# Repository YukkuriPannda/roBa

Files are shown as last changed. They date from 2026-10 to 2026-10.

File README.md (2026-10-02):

# roBa

## 個人用ケース改造（FreeCAD / PLA）

このフォークではroBa v3を基準に、既存の折り畳みテンティング案をFreeCADで編集・再生成できる構成へ移植しています。

- [FreeCAD版の起動・編集・出力](case/v3/freecad/README.md)
- [自然言語の要望から改造する手順とデータの役割](doc/freecad-workflow.md)
- [PLAの強度チェック・解析・試し刷り](doc/pla-strength-check.md)

基準STEPを保持し、追加形状をパラメーターで管理します。CAD検査の合格と、PLAで印刷した実物の強度・嵌合確認は別に記録します。

roBaは[keyball](https://github.com/Yowkees/keyball/)に影響を受けたワイヤレスキーボードです  


開発時のブランチ、コミット、承認ルールは[開発・Git運用ガイド](CONTRIBUTING.md)を参照してください。

特徴:
+ ZMK firmwareによるbluetooth(BLE)対応
+ 分割カラムスタッガード配列(キー数:42)
+ トラックボール搭載
+ 水平ロータリーエンコーダ搭載（v1: evqwgd001, v2以降: [CKW12](https://github.com/kumamuk-git/CKW12/tree/main)）

## Where to Buy

[BOOTH](https://kumamuk.booth.pm/)にて組み立てキットが購入可能

## Build Guide

ビルドガイドは[こちら](https://github.com/kumamuk-git/roBa/blob/main/doc/v3/buildguide_v3.md)

## Firmware

ファームウェアのリポジトリは[こちら](https://github.com/kumamuk-git/zmk-config-roBa)  
デフォルトでは以下のように設定されています
+ オートマウスレイヤー：4
+ スクロールレイヤー：5  
+ CPI：400

ファームウェア、キーマップの編集手順は[こちら](https://github.com/kumamuk-git/roBa/blob/main/doc/v3/buildguide_v3.md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)  
（ZMK STUDIOでもキーマップ編集可能）

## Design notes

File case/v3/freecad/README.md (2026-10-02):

# roBa v3 FreeCAD ネイティブワークフロー

このフォルダーでは、既存のピンレス折りたたみスタンドと底面側ハードウェアを FreeCAD の `Part` API で再構築します。`case/v3/bottom_L.stp`、`bottom_R.stp`、`top_L.stp`、`top_R.stp` は読み込み専用の参照形状として保持し、元の STEP ファイルや `case/v3/tenting/` 内のファイルは変更しません。

## ビルドと検証

リポジトリのルートで、FreeCAD 1.1 に同梱されている Python を実行します。

```powershell
$freecadBin = Join-Path $env:LOCALAPPDATA 'Programs\FreeCAD 1.1\bin'
& (Join-Path $freecadBin 'python.exe') 'case\v3\freecad\build_verify.py'
```

このコマンドは FreeCAD Python を別プロセスで起動し、FCStd の作成と保存、再オープン後の寸法変更テスト、再度の再オープンと最終検証・エクスポートを行います。成功すると `generated\freecad_build.verified.json`、部品ごとの検証記録、STEP/STL、`generated\roba_v3_folding_tenting.FCStd` を生成します。直近の実行結果は `generated\latest_run_status.json` に記録されます。失敗した場合は直前に成功した成果物を残し、ステータスを `FAIL` にします。残っている成功マニフェストはそこに記載されたハッシュ付き成果物を示すもので、失敗した実行の成果物ではありません。

FreeCAD 同梱の Python を使用し、CadQuery は読み込みません。ビルドには元の STEP ファイルと、既定寸法との回帰確認に使う `case/v3/tenting/output/*.verified.json` が必要です。形状、体積、バウンディングボックス、端点姿勢での干渉、STEP の再読み込み比較、STL メッシュの閉鎖性のいずれかが検査に失敗すると、新しい成果物の公開を中止します。

## ネイティブモデルを開いて編集する

生成後の独立した出力検査と、編集後の出力・不正寸法の拒否は次で再確認できます。後者は `tests/custom-check/` に試験専用のコピーを作り、標準成果物を変更しません。

```powershell
& (Join-Path $freecadBin 'python.exe') 'case\v3\freecad\tests\check_exports.py' .
& (Join-Path $freecadBin 'python.exe') 'case\v3\freecad\tests\check_custom_export.py' .
```

FreeCAD の Macro メニューから `Open_FreeCAD.FCMacro` を実行します。このマクロは FCStd を開く前にこのフォルダーを Python のモジュール検索パスへ追加し、保存済み形状を再計算する `roba_freecad` のプロキシを読み込めるようにします。FCStd がまだない場合は既定寸法のモデルを作成して保存します。初期表示は左側ケースのみです。ツリーでスタンド、右側ケース、上面参照形状を選択して Space キーを押すと、それぞれの表示／非表示を切り替えられます。

`Tenting dimensions (mm / degrees)` オブジェクトに名前付き寸法がまとまっています。`FoldingStand`、`BottomLHardware`、`BottomRHardware` は寸法プロパティに応じて形状を作り直す Python FeaturePython オブジェクトです。`BottomLTenting` と `BottomRTenting` は、再計算された追加ハードウェアを元の底面形状へ結合します。元の左右底面と上面は、それぞれのモデル／参照グループ内に独立した `Part::Feature` のスナップショットとして残ります。STEP を読み込むことで BRep 形状は保持されますが、元のスケッチやフィーチャー履歴は復元されません。

寸法を編集して書き出す場合は、先に FCStd を保存し、FreeCAD の Python コンソールで次を実行します。

```python
from roba_freecad import export_current_document
export_current_document(App.ActiveDocument)
```

このエクスポート処理は、現在の寸法と再計算後の形状を検証してから成果物を更新します。寸法が範囲外の場合や形状検査に失敗した場合はエクスポートを停止し、`generated/latest_run_status.json` に `FAIL` を記録します。

`BaseTentAngle` と元の底面に由来する下面 Z 座標は、既存ケースに対する固定座標変換の参照値です。プロパティエディターでは読み取り専用ですが、Python から意図的に変更すると追加ハードウェアの配置が変わります。読み込んだケース形状そのものは角度変更で回転しません。`DeployAngle` はクリアランス検査に使う端点姿勢だけを指定します。この値を変えても実際のカムストップ形状は変わりません。`NominalTotalTentAngle` は表示用の目標値で、形状を駆動する寸法ではありません。

## 検証の範囲

自動検証では、BRep の有効性と単一ソリッド性、既定寸法での既存検証記録との回帰、元の底面材料が失われていないこと、ピン・ボア・スロートの寸法、折りたたみ／展開の端点姿勢での干渉、STL メッシュの閉鎖性を確認します。STEP 再読み込みでは、体積差を相対 0.02% 以内、`optimalBoundingBox(False, False)` の各辺長の差を 0.02 mm 以内、BRep 頂点とテッセレーション頂点の双方向サンプル距離を 0.005 mm 以内に確認します。これらはサンプルと寸法の回帰確認であり、完全な形状同一性の証明ではありません。ヒンジの全可動範囲は解析しません。また、実機との適合、PLA/PETG の強度、疲労寿命、スナップ力、スライサー挙動、印刷可能性を証明するものではありません。これらは別途レビューと実物での試験が必要です。

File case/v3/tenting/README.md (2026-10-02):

# v3 折り畳み式テンティングスタンド

roBa v3 の左右底面に、別部品のピンやネジを使わない折り畳みスタンドを追加します。左右それぞれの構成部品は、ヒンジ受けを一体化したケース底面と、左右共通のスタンドの2点です。

## 設計条件

- 既存の `bottom_L.stp` / `bottom_R.stp` を正とし、元形状には穴あけや切削を行わない
- ケース側のC形受けへ、スタンド一体の直径3.0 mm軸を押し込むスナップ式ヒンジ
- 軸と受けの半径クリアランスは0.20 mm、挿入口の干渉は直径方向で0.35 mm
- 収納時は2つのボールデテント、展開時はスタンド一体のカムで65度に止める
- v3底面の既存4度と合わせ、支持間隔110 mmで公称約15度
- 左右のスタンド形状は共通。ネジ、金属ピン、磁石は不要

## 生成

CadQuery 2.8以降で次を実行します。

```powershell
python .\case\v3\tenting\build_tenting.py
```

`output` に左右のケース底面と共通スタンドのSTEP/STL、および検証記録を出力します。

## 造形と組み立て

スタンドは広い面を造形ベッドへ向け、ケース底面は従来どおり外面を下にして造形する想定です。ケース側のC形受けへスタンド軸を真下から均等に押し込みます。材料や積層方向によってスナップ量が変わるため、初回は受け1個分の試し刷りを推奨します。

実機荷重、繰り返し開閉寿命、机上での滑り、およびスライサー上のサポート要否は未確認です。

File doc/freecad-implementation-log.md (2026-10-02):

# FreeCAD移植の確認記録（2026-10-02）

個人フォークの専用チェックアウト `C:\Users\Pannda\Documents\Codex\roBa-freecad`、ブランチ `feat/freecad-workflow` で作業した。既存の `case/v3/tenting/` をコピーして引き継ぎ、元のv3 STEPを保持した。この文書は移植検証の記録であり、形状変更とFreeCAD対応は別コミットで管理する。Git統合の履歴はGitログを参照する。

## 作成したもの

- `case/v3/freecad/`: FreeCAD Part APIの生成コード、起動マクロ、FCStd、STEP/STL、検査記録、独立した検査スクリプト。
- `doc/freecad-workflow.md`: データの役割、自然言語の要望から設計条件を固める手順、変更・検査・復旧の流れ。
- `doc/pla-strength-check.md`: 印刷仮条件、形状・肉厚・造形方向の確認、解析対象、試験片・開閉・荷重保持の判定。
- READMEとAGENTS.md: 利用者向けの入口と、今後のAI改造作業ルール。

元ケースはSTEPの参照形状として保持し、脚・受け・デテント配置を名前付き寸法で再計算する。デテント曲面は旧STEPから回収したBRepを使う。元CADのスケッチ履歴は復元していない。

## 実行した確認

FreeCAD同梱Python、FreeCAD 1.1.4で確認した。

| 確認 | 結果 |
|---|---|
| `build_verify.py` | PASS。生成、別プロセスでの再読込・寸法変更・復元、最終再読込・出力 |
| BRep | 脚・左右の改造底面は有効な単一ソリッド。元底面の材料を保持 |
| 収納／展開端点 | 既存案の干渉上限2 mm³以内。全可動範囲の証明ではない |
| STL | 脚824面、左6230面、右7072面。閉鎖性、辺の多様体性、面の向き、縮退面検査に合格 |
| STEP再読込 | 体積相対差0.02%以内、解析形状の外形差0.02 mm以内、双方向のサンプル距離0.005 mm以内 |
| 独立した旧形状との比較 | 双方向の表面サンプル距離の最大値は約8.17e-8 mm。サンプル比較であり完全同一性の証明ではない |
| 編集後の出力 | 脚長20→21 mmで再計算・保存・出力に合格。標準出力を変更しない試験用コピーで実行 |
| 不正寸法 | 軸半径2 mm・受け半径1.7 mmの矛盾を拒否。直前の出力を保持し、最新状態をFAILとして記録 |
| 保存内容と記録 | 編集後のFCStdハッシュと出力記録が一致。開き直すと採用した脚長21 mm・元の軸半径1.5 mmを保持 |
| 配布場所への移動 | 一式を別フォルダーへコピーし、成果物ハッシュ、相対パス、FCStd再読込と厚み変更の再計算に合格 |

旧STEPをFreeCADで書き出し直すと、変更のない元底面でも体積値に約2.547 mm³の差が出た。境界上のサンプル点はほぼ一致したため、体積完全一致の判定をやめ、相対差・解析境界箱・双方向の点と形状の距離を組み合わせた。境界箱は表示用三角形キャッシュに影響されない `optimalBoundingBox(False, False)` を使う。

再確認コマンドは[操作手順](../case/v3/freecad/README.md)を参照。詳細な数値とハッシュは `case/v3/freecad/generated/freecad_build.verified.json` に保存した。配布用コピーには独立した検査と編集後の出力試験のJSONも添付した。

## 未確認事項

FreeCAD GUIでの実操作、手元のケース世代の確定、PCB・電池・配線など内部品との実物嵌合、ヒンジ途中の全動作、スライサー、試し刷り、PLAの荷重・疲労・クリープ・耐熱性は未確認。FEM解析も未実施。プリンター、PLA製品、実際の荷重条件が決まるまでは強度の最終合格を出さない。

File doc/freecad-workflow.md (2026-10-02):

# 個人用roBa v3ケースの改造

対象はv3通常トップと左右底面。実物の世代は暫定なので、印刷前に爪・穴・PCB・トラックボール周辺を照合する。既存の折り畳みテンティング改造を引き継ぎ、FreeCADで追加形状を変更できるようにする。

## データの役割

| データ | 役割 |
|---|---|
| `case/v3/*.stp` | 上流由来の基準形状。直接上書きしない |
| `case/v3/tenting/` | 引き継いだCadQuery版と過去の検査記録。比較・参照用 |
| `case/v3/freecad/` | FreeCAD版の生成コード、マクロ、ネイティブ文書、検査結果 |
| `.FCStd` | 基準形状、パラメーター、追加形状を保持する編集用文書 |
| STEP / STL | 交換用 / スライサー用の出力。編集元にはしない |

元のSTEPには元CADのスケッチ履歴が含まれない。FreeCADへの移植でその履歴が復元されるわけではない。基準形状を保持し、新規の機能を再計算できる履歴として追加する。生成コードと寸法が再現用の正本で、FCStdを手で変更した場合は採用する値をコードへ戻して再生成する。手作業だけの変更を再生成で消さないよう、先に別名保存する。

収納デテントの曲面は、旧STEPから取り出したBRepを参照形状として保持する。FreeCADの標準ロフトで曲面を作り直すと旧形状に差が出るため、今回は元の曲面を維持し、取り付け位置をパラメーターで変更する。デテント自体の曲面・半径の再設計は別の変更として扱う。

FreeCAD Pythonの外部モジュールを使う文書は、モジュールが見つかる環境で開く必要がある。FCStdだけを別のPCへ渡して編集可能と扱わず、生成コードと起動マクロも一緒に渡す。具体的な起動・再生成手順は[FreeCAD版のREADME](../case/v3/freecad/README.md)を参照。

## 自然言語の要望から変更する

「磁石を付けたい」「脚の角度を変えたい」などの要望を出発点にする。AIは既存データを調べ、次の設計カードを埋めてから変更する。見た目から決められる軽微な値は仮定を明記し、部品寸法・使用荷重・嵌合など結果を左右する不明点は質問する。

```text
目的 / 使用場面:
対象パーツ / 左右:
機能と取り付け位置:
寸法 / 可変範囲 / 根拠:
維持する穴・爪・接触面:
相手部品の寸法 / 公差:
荷重 / 荷重方向 / 繰り返し / 温度:
印刷プロファイルID / 造形方向:
形状の受入条件:
強度の受入条件 / 試し刷り方法:
未確定事項:
```

作業は目的別ブランチで行い、基準形状から追加機能を分け、意味のある名前とmm・度単位を付ける。左右の構造差を確認し、全体を単純ミラーしない。PCB、電池、配線、スイッチ、エンコーダ、USB、トラックボール、底面の爪との干渉を検査する。実物の位置が分からない箇所は「未確認」と記録する。

変更ごとに再生成、形状検査、再読み込み、主要寸法の編集・再計算を確認する。画像と検査記録を残し、[PLA強度チェック](pla-strength-check.md)に沿って解析・試作の要否を判断する。失敗時は直前のFCStdを戻すか、採用済みパラメーターから再生成する。検査失敗した出力を印刷候補として扱わない。

## 引き継ぐテンティング機構

既存案は軸直径3.0 mm、受け内径3.4 mm、挿入口2.65 mm、脚厚2.7 mm、展開角65度。支持間隔110 mmと既存底面角4度を使った公称傾斜は約15度。寸法は既存案を再現するための値で、PLAでの耐久性が確認された値ではない。

収納デテントの球半径1.5 mmに対し穴半径1.4 mmで意図的な干渉がある。ヒンジ挿入口も軸より狭い。したがって干渉体積ゼロだけを合格条件にせず、収納・展開・回転途中の接触位置と試し刷りを確認する。既存コードの端点干渉上限2 mm³は再現比較の基準で、機構の安全性・開閉可能性を証明しない。

## リポジトリ運用

同じ個人フォークを使う専用チェックアウトは `C:\Users\Pannda\Documents\Codex\roBa-freecad`。元の `D:\OtherProjects\roBa-case` の未追跡データは保持する。公開・push・mainへのマージは[開発ガイド](../CONTRIBUTING.md)の対象別承認に従う。元のライセンスと、トラックボールケースの[出典・帰属](../case/README.md)を保持する。

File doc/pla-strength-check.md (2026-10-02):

# PLAケースの強度チェック

この文書は個人用の試作判定手順。形状の合格、解析上の合格、試作の合格を別に記録する。プリンター、PLA製品、ノズル、荷重が未確定の現在は、強度の最終合格を出さない。

## 印刷条件を固定する

記録する項目はプリンター・ノズル径・実際の線幅・層高・フィラメント製品とロット・乾燥状態・温度・冷却・外周数・上下層厚・インフィル・造形方向・サポート・スライサーとプロファイル版。部品ごとの造形方向は画像でも残す。

初回の比較用仮条件はノズル0.4 mm、層高0.2 mm、外周4本、上下層厚1.0 mm以上、インフィル30%。温度は製品メーカーの指定範囲とプリンターの検証済みプロファイルを使う。これは検証の出発点として本プロジェクトが選ぶ条件であり、強度保証値ではない。実機情報が分かったら置き換える。

## 毎回の確認

| 確認 | 判定・対処 |
|---|---|
| BRep | 最終部品は有効で期待するソリッド数。元形状を保持する追加改造では `元形状 - 改造形状` の体積が数値許容差内でゼロ |
| 出力メッシュ | 閉じたメッシュ、非多様体・縮退面・反転を確認。できない検査は未確認とする |
| 寸法・嵌合 | 外形、穴、爪、相手部品、左右、組み付け経路を確認。公差は試験片で決める |
| 肉厚 | 新規の剛性壁は実線幅4本分、荷重を受ける付け根は6本分を初回レビュー目安にする。満たしても自動合格にはしない |
| 薄肉・局所部 | 薄い爪・ヒンジ・孔周辺は局所断面と最薄部を測る。スナップは上の剛性壁基準と分け、必要変位・ひずみを確認 |
| 応力集中 | 脚・ボス・ヒンジの付け根に補強と丸みを検討。薄い首、鋭い内角、孔間の短い残肉を重点確認 |
| 積層方向 | 曲げや引張で層間が開く方向を避ける。スライサーで外周の連続性、空洞、サポート除去経路を確認 |
| 接触と動作 | 収納、展開、途中の動作、ストッパー、ガタ、脱落、机上の滑りを確認 |

全体の自動肉厚検査がない場合、代表点の確認だけで全体合格としない。重点箇所の測定表と断面画像を残す。変更した寸法の連動で爪・相手部品・クリアランスが変わる場合は再検査する。

## 解析が必要になる変更

支持脚、ヒンジ、ストッパー、ネジボス、手荷重を受ける部位、長い片持ち、肉薄化、材料や造形方向の変更は解析対象の候補。今回の折り畳み脚は対象に含める。小さな飾りや荷重を受けない配置変更は、理由を記録して解析を省略できる。

先に使用時の力・方向・位置、支持点、両脚への分配、組立時の押し込み力、繰り返し回数、使用温度を設計カードに書く。未定なら荷重を仮定して感度を調べることはできるが、最終合格は保留する。

FreeCAD FEMを使う場合はソルバー・メッシュ・拘束・接触・材料定数を保存する。材料は製品データと同条件の試験片を優先し、汎用PLAの等方性材料は予備比較に限定する。Z方向の弱さ、クリープ、疲労は等方性の静解析だけでは判定できない。スナップ組立は大変形・接触があるため、小変形の静解析だけで可否を決めない。

強度の数値判定には同条件の根拠ある許容値を使い、初回の目標安全率を2以上とする（本プロジェクトの暫定方針）。許容値の根拠がない場合は応力・変位の比較結果のみ報告する。変位限界はPCB、接触部、ガタの許容値から決める。メッシュを細かくした結果も比較し、応力特異点と実際の破損候補を分ける。

## 試し刷りと実物判定

最初は実際と同じ造形方向でヒンジ受け・軸・デテントの小片を印刷する。押し込みで白化・割れ・層間剥離が出たら不合格。寸法または機構を見直し、無理に押し込まない。

小片の後に全体を印刷し、実物への嵌合、収納・展開、ストッパー、安定性を確認する。合意した使用荷重を段階的に加え、初回の試作では100回の開閉と24時間の使用荷重保持を記録する。これは初期不具合を探すスクリーニングで、耐用寿命の保証ではない。試験中の支持を確保し、基板・電池を破損させない構成で行う。

割れ、白化、永久変形、層間剥離、脚の脱落、ストッパー越え、使用に支障のあるガタは不合格。試験前後の寸法と写真、荷重、温度、開閉回数を記録する。造形条件を変えたら関連する試験をやり直す。

## 記録テンプレート

```text
変更ID / コミットまたはコードハッシュ:
対象 / FCStd / STEP / STL:
印刷プロファイルID / フィラメント:
形状: 合格 / 不合格 / 未確認（検査結果・断面画像）
荷重条件 / 温度 / 目標寿命:
解析: 合格 / 不合格 / 比較のみ / 省略（根拠・結果）
試験片: 合格 / 不合格 / 未実施
実物嵌合 / 開閉 / 荷重保持: 合格 / 不合格 / 未実施
総合: 試作候補 / 使用条件内で確認済み / 不合格
未確認事項 / 次の確認:
```

## 参考資料

PLAの脆さ・柔軟性と耐熱性の制約は[PrusaのPLA解説](https://help.prusa3d.com/article/pla_2062)、外周数の強度への影響は[Layers and perimeters](https://help.prusa3d.com/article/layers-and-perimeters_1748)を参照。本書の肉厚目安、印刷仮条件、安全率、試験回数はプロジェクトの暫定基準で、これら資料が保証した基準ではない。

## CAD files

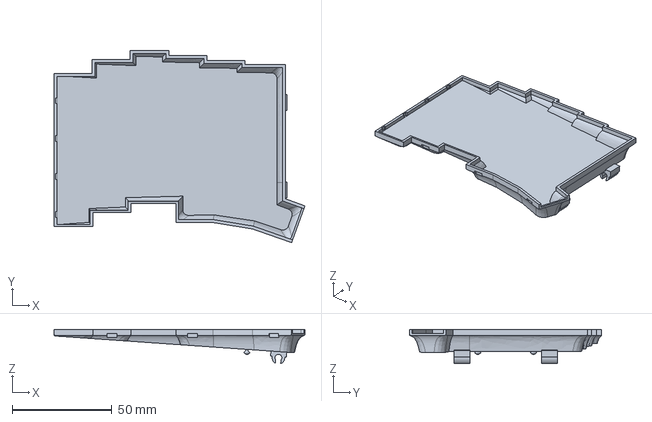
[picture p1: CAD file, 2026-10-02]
case/v3/freecad/generated/bottom_L_tenting.stp
126.1 x 96.6 x 17.2 mm

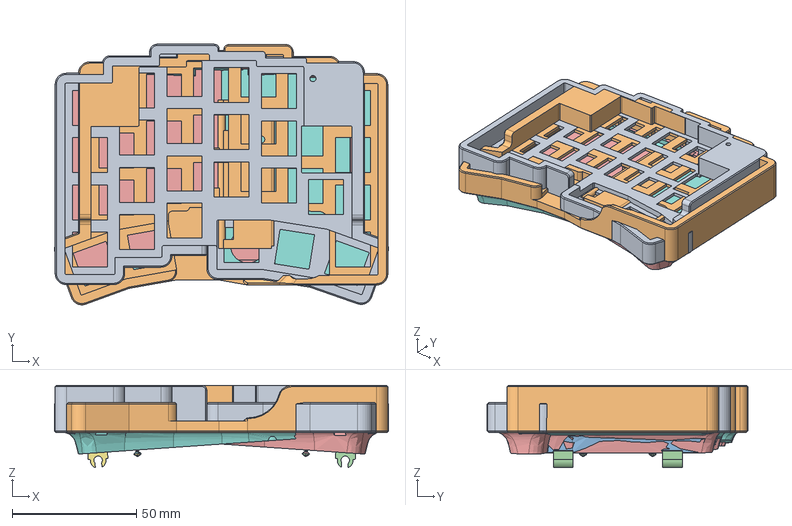
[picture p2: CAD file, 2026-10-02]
case/v3/freecad/generated/roba_v3_folding_tenting.FCStd
134.6 x 105.0 x 33.2 mm
Legacy detent loft BRep seed (fixed profile)
Universal folding stand
bottom_L.stp (imported STEP snapshot)
bottom_L_tenting added sockets and detents
bottom_L_tenting
bottom_R.stp (imported STEP snapshot)
bottom_R_tenting added sockets and detents
bottom_R_tenting
top_L.stp (imported reference snapshot; no recovered sketch history)
top_R.stp (imported reference snapshot; no recovered sketch history)

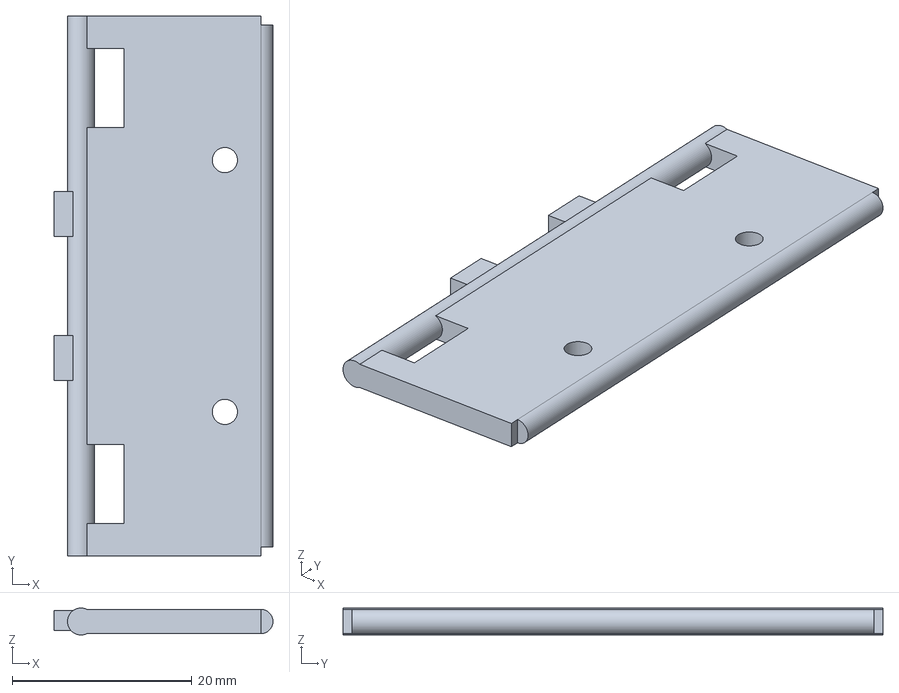
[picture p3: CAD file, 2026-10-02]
case/v3/tenting/output/folding_tenting_stand.stp
24.4 x 60.0 x 3.00 mm

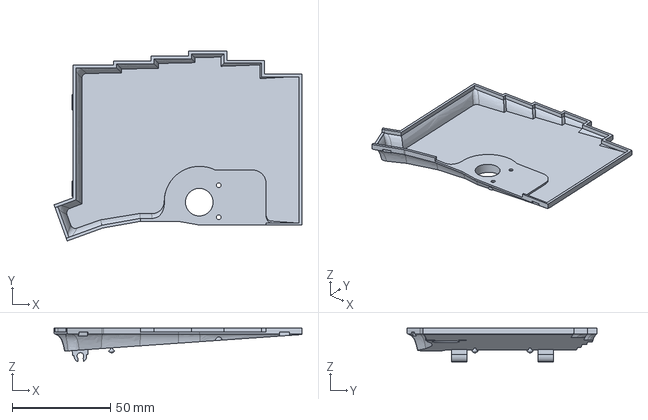
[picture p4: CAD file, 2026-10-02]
case/v3/tenting/output/bottom_R_tenting.stp
125.9 x 96.5 x 17.2 mm

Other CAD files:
case/v3/tenting/output/bottom_L_tenting.stp
case/v3/freecad/generated/folding_tenting_stand.stp
case/v3/freecad/generated/bottom_R_tenting.stp
case/v3/freecad/generated/bottom_L_tenting.stl
case/v3/freecad/generated/bottom_R_tenting.stl
case/v3/freecad/generated/folding_tenting_stand.stl
case/v3/tenting/output/bottom_L_tenting.stl
case/v3/tenting/output/bottom_R_tenting.stl
case/v3/tenting/output/folding_tenting_stand.stl

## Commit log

2026-09-15 docs: Git運用と作業ルールを整備
2026-10-02 roBa v3に折りたたみテンティング脚と改造ケースを追加
    [bottom_L_tenting.stl, bottom_L_tenting.stp, bottom_R_tenting.stl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]
2026-10-02 FreeCADの再計算・出力検査とPLA改造ルールを整備
    [bottom_L_tenting.stl, bottom_L_tenting.stp, bottom_R_tenting.stl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]
2026-10-03 feat(case): 34mmベアリングケースを追加
2026-10-03 fix(case):COROPITを継承するように
2026-10-13 chore(case): 未使用の旧ジェネレーターtrackball_bearing.pyを削除
2026-10-13 feat(case): ベアリングケースを印刷向けに調整し支持点を再配置
    - 支持点を極角61度・方位139/259/19度へ変更（反力0.688均等、条件数1.28）
    - 横穴のティアドロップ化、3水準の嵌合試験片、印刷用STLとPRINT.mdを追加
    - 印刷用STL書き出しでfloat32丸めによる自己交差を微小XYシフトで回避
    - PLA強度の手計算チェックを追加（判定HOLD: 球側ウェブ0.58mm）
    - ベアリング位置マーカー付き6面図を追加
    CAD検査58/58合格、物理検証・強度は未確認。
2026-10-13 feat(case): ベアリングをミニ四駆620・M2ビスへ変更し球側ウェブを補強
    - ベアリング: タミヤ620（内径2×外径6×幅2mm）、中心距離20mm
    - ビス: M2×6mm、下穴1.65mm、スペーサー0.5mm（外径2.9・内径2.1）
    - 球側ウェブ 0.58mm → 1.84mm（目標1.6mmを満たす）
    - 球中心・センサー周り・支持角度（61度、139/259/19度）は不変
    - 強度手計算: 先端集中荷重モデルで10N時SF 2.74（判定はHOLDのまま）
    CAD検査58/58合格。ビス頭寸法・スペーサー寸法は仮定値、物理検証は未実施。
2026-10-13 docs(case): READMEの生成コードハッシュを最新実行に更新
2026-10-16 docs(agents): SolidCraft運用・サブエージェント規則と画像つき報告スキルを追加
    - AGENTS.md: Claude Code内のモデル割り当て（決断はOpus、実務はHaiku/Sonnet）とSolidCraft運用を追記
    - CLAUDE.md: AGENTS.mdを読み込むだけの1行
    - .mcp.json: SolidCraft MCPサーバー（solidcraft/以下に限定）
    - .claude/skills/cad-visual-report: 3面図・寸法照合・確認状況を1枚のHTMLにまとめる報告スキル
    Claude-Session: https://claude.ai/code/session_01CSYVcHRb6K8thh19qxMuhF
2026-10-16 feat(solidcraft): PCBスライドケースをSolidCraftコマンドスクリプトへ移植
    - slide_case.json: 5つの名前付きパラメータで決まるケース本体とスライド蓋
    - build.ps1: STEP/STL/3MF/スナップショット/計測JSONを出力
    - 外形・体積は手計算と一致（本体106x106x62.6、蓋99.4x102.7x3）
    - 未確認: スライド途中の干渉、FreeCAD版との体積比較、スライサー、実物嵌合
    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
